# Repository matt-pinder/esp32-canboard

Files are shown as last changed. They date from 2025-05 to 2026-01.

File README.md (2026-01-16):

# ESP32-CANBoard
* ESP32-S3 Dual Core SoC
* MCP2562T CAN Transceiver (up to 1Mbps)
* 10x 5v Tolerant Inputs - Pressure Sensors, NTCs, etc
* 2x 5v Outputs - Fused at 500mA (Thermal Reset)
* USB-C for programming, with JTAG support for debugging
* ESD Protection on both USB and CAN
* JAE Automotive Connector (PCB Socket: MX23A18NF1, Cable Plug: MX23A18SF1)
* Optional pull-up resistors via fused 5v rail for each input (TH 6.3mm)
* Optional 120ohm CAN terminating resistor
* Configuration via web interface over WiFi
* Optional per-channel median filtering to reduce noise
* Small PCB Footprint - 40mm x 60mm

## Device Configuration

On each boot the board enables a WiFi access point and web configuration interface; this will automatically disable after 120 seconds if no client connects. 

| SSID | WPA2 Key | Web UI |
|:---|:---|:---|
| ESP32-CanBoard | canboard123 | http://192.168.4.1 |

The web UI allows you to:

- View and edit per-channel settings (name, sensor type, pull-up, filtering, pressure calibration).
- Configure required CAN parameters - Base ID and bus speed.
- Adjust pullup vref calculation voltage to allow for LDO regulator output/load.
- Backup the entire configuration to a JSON file.
- Restore configuration from a previously exported JSON file.

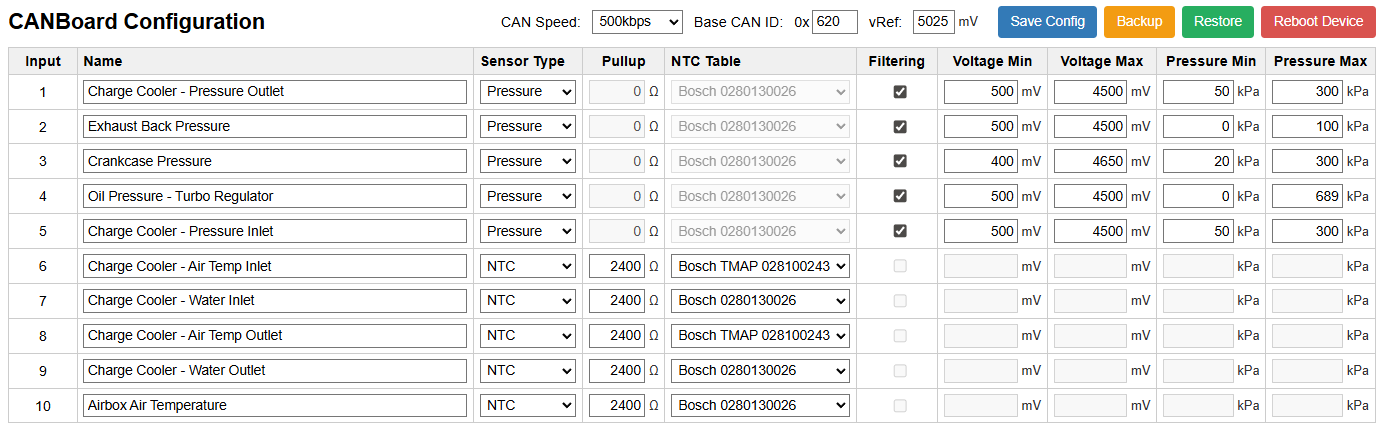
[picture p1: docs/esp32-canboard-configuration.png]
esp32-canboard-configuration


| Function | Description |
|:----|:----|
| Save Config | Save current UI settings to device storage (`/spiffs/config.bin`). Changes are validated and persisted immediately, reboot to apply. |
| Backup | Download a JSON snapshot of the current configuration. The filename is prefixed with `esp32-canboard-config-` and suffixed with the client timestamp in `ddmmyy-hhmmss` format. |
| Restore | Select a previously exported JSON file. The UI will upload the JSON to the device and validate the payload. The existing configuration is backed up on the device before overwrite; if saving the imported file fails, the device will restore the previous configuration. |
| Reboot Device | Reboots the device to apply configuration changes. |

**Notes:**
- Configuration is persisted on SPIFFS at `/spiffs/config.bin` (binary) and the web UI uses JSON export/import for human-readable backups.
- After restoring a new configuration via the web UI you should reboot the device to apply changes.

## CAN Output

The device transmits input data as a set of five CAN frames starting at the configured base ID. All frames use DLC=8 and little-endian byte ordering.

| CAN ID | Name | Payload |
|:---|:---|:---|
| Base ID | analogVoltage_1 | Inputs 0..3 as four uint16 (LSB,MSB) — bytes 0..7 (values in mV) |
| Base ID + 1 | analogVoltage_2 | Inputs 4..7 as four uint16 (LSB,MSB) — bytes 0..7 (values in mV) |
| Base ID + 2 | analogVoltage_3 | Inputs 8..9 as two uint16 (bytes 0..3), dynamic0 (bytes 4..5), dynamic1 (bytes 6..7) |
| Base ID + 3 | dynamicSignals_1 | dynamic2, dynamic3, dynamic4, dynamic5 as four 2-byte values (bytes 0..7) |
| Base ID + 4 | dynamicSignals_2 | dynamic6, dynamic7, dynamic8, dynamic9 as four 2-byte values (bytes 0..7) |

Encoding rules for dynamic values (one per input):
| Channel | Type | Encoding |
|:---|:---|:---|
|analogVoltage|-|unsigned uint16 = voltage * 1000 (resolution 0.001 V)|
|dynamicSignal|Raw|unsigned uint16 = **0** use analogVoltage signal instead|
|dynamicSignal|Pressure|unsigned uint16 = pressure_kPa * 100 (resolution 0.01 kPa)|
|dynamicSignal|NTC|signed int16 = temperature_C * 1 (°C as integer)|

Example DBC for signal names and scaling: [dbc/esp32-canboard.dbc](dbc/esp32-canboard.dbc)

## Schematic
[View PDF](docs/esp32-canboard-schematic.pdf)

## Images
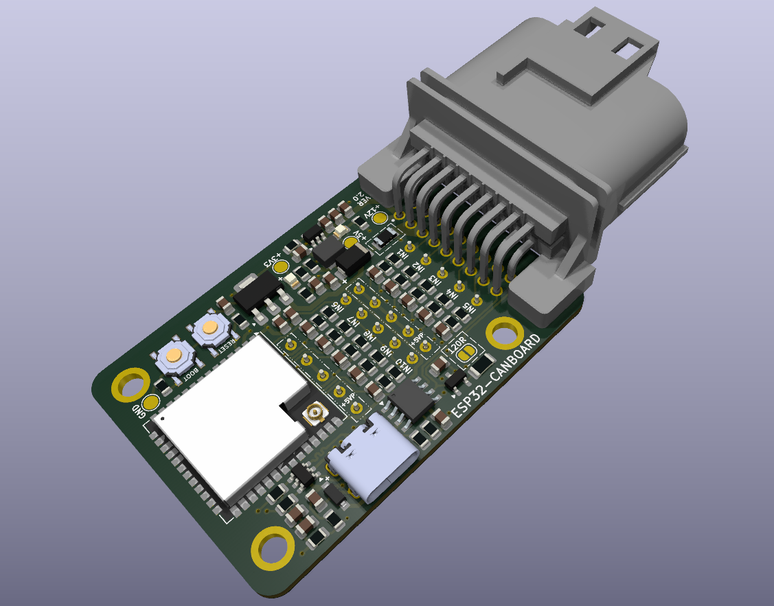
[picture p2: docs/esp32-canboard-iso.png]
esp32-canboard-iso


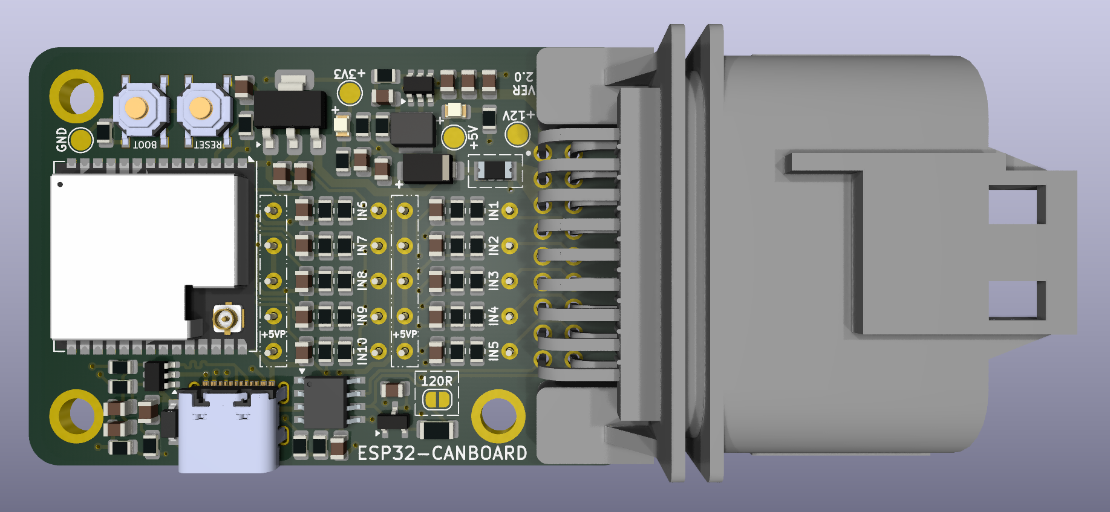
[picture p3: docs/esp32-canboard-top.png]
esp32-canboard-top


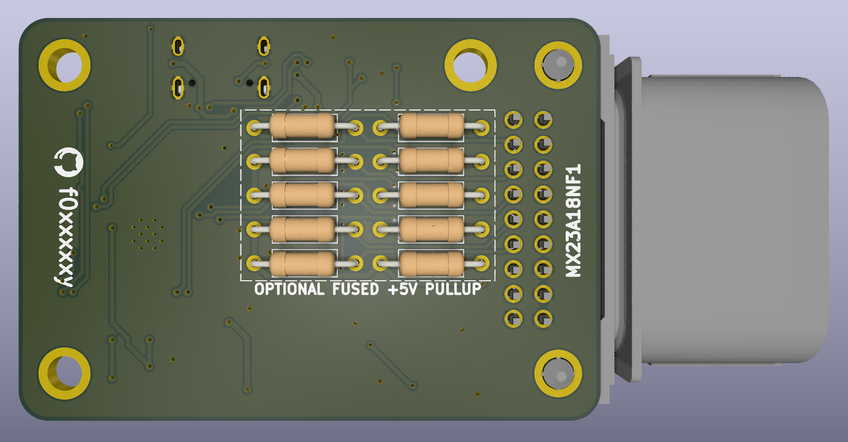
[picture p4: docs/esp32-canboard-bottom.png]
esp32-canboard-bottom


## Connector Pinout
|Pin|Function|Additional Information|
|:---:|:---|:---|
|1|12v Supply||
|2|5v Sensor Supply|500ma Thermal Fuse|
|3|5v Sensor Supply|500ma Thermal Fuse|
|4|Input 6||
|5|Input 7||
|6|Input 8||
|7|Input 9||
|7|Input 10||
|9|CAN High||
|10|Ground||
|11|Ground||
|12|Ground||
|13|Input 1||
|14|Input 2||
|15|Input 3||
|16|Input 4||
|17|Input 5||
|18|CAN Low||

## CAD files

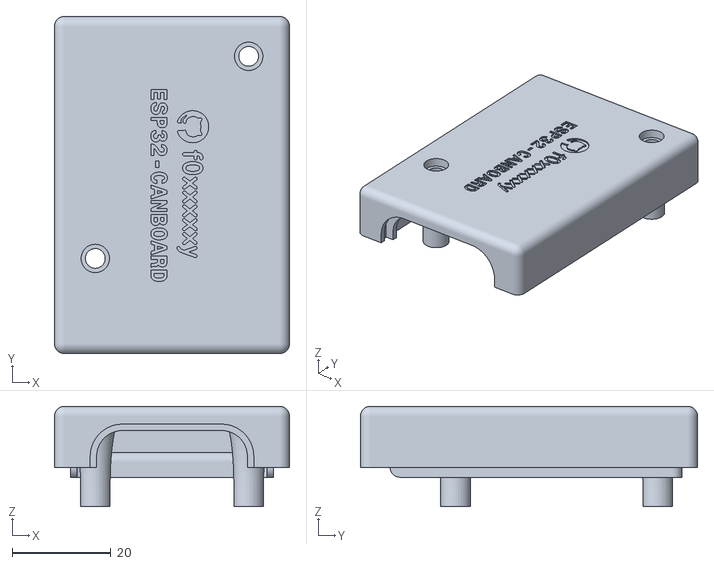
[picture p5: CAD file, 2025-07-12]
hardware/esp32-canboard-case-top.STL
47.5 x 68.2 x 20.3

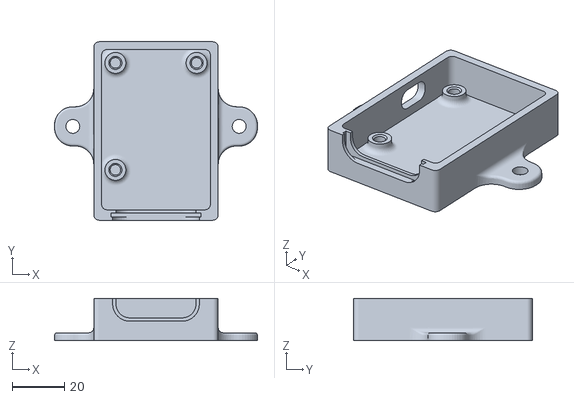
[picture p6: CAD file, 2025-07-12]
hardware/esp32-canboard-case-bottom.STL
77.5 x 68.2 x 16.1

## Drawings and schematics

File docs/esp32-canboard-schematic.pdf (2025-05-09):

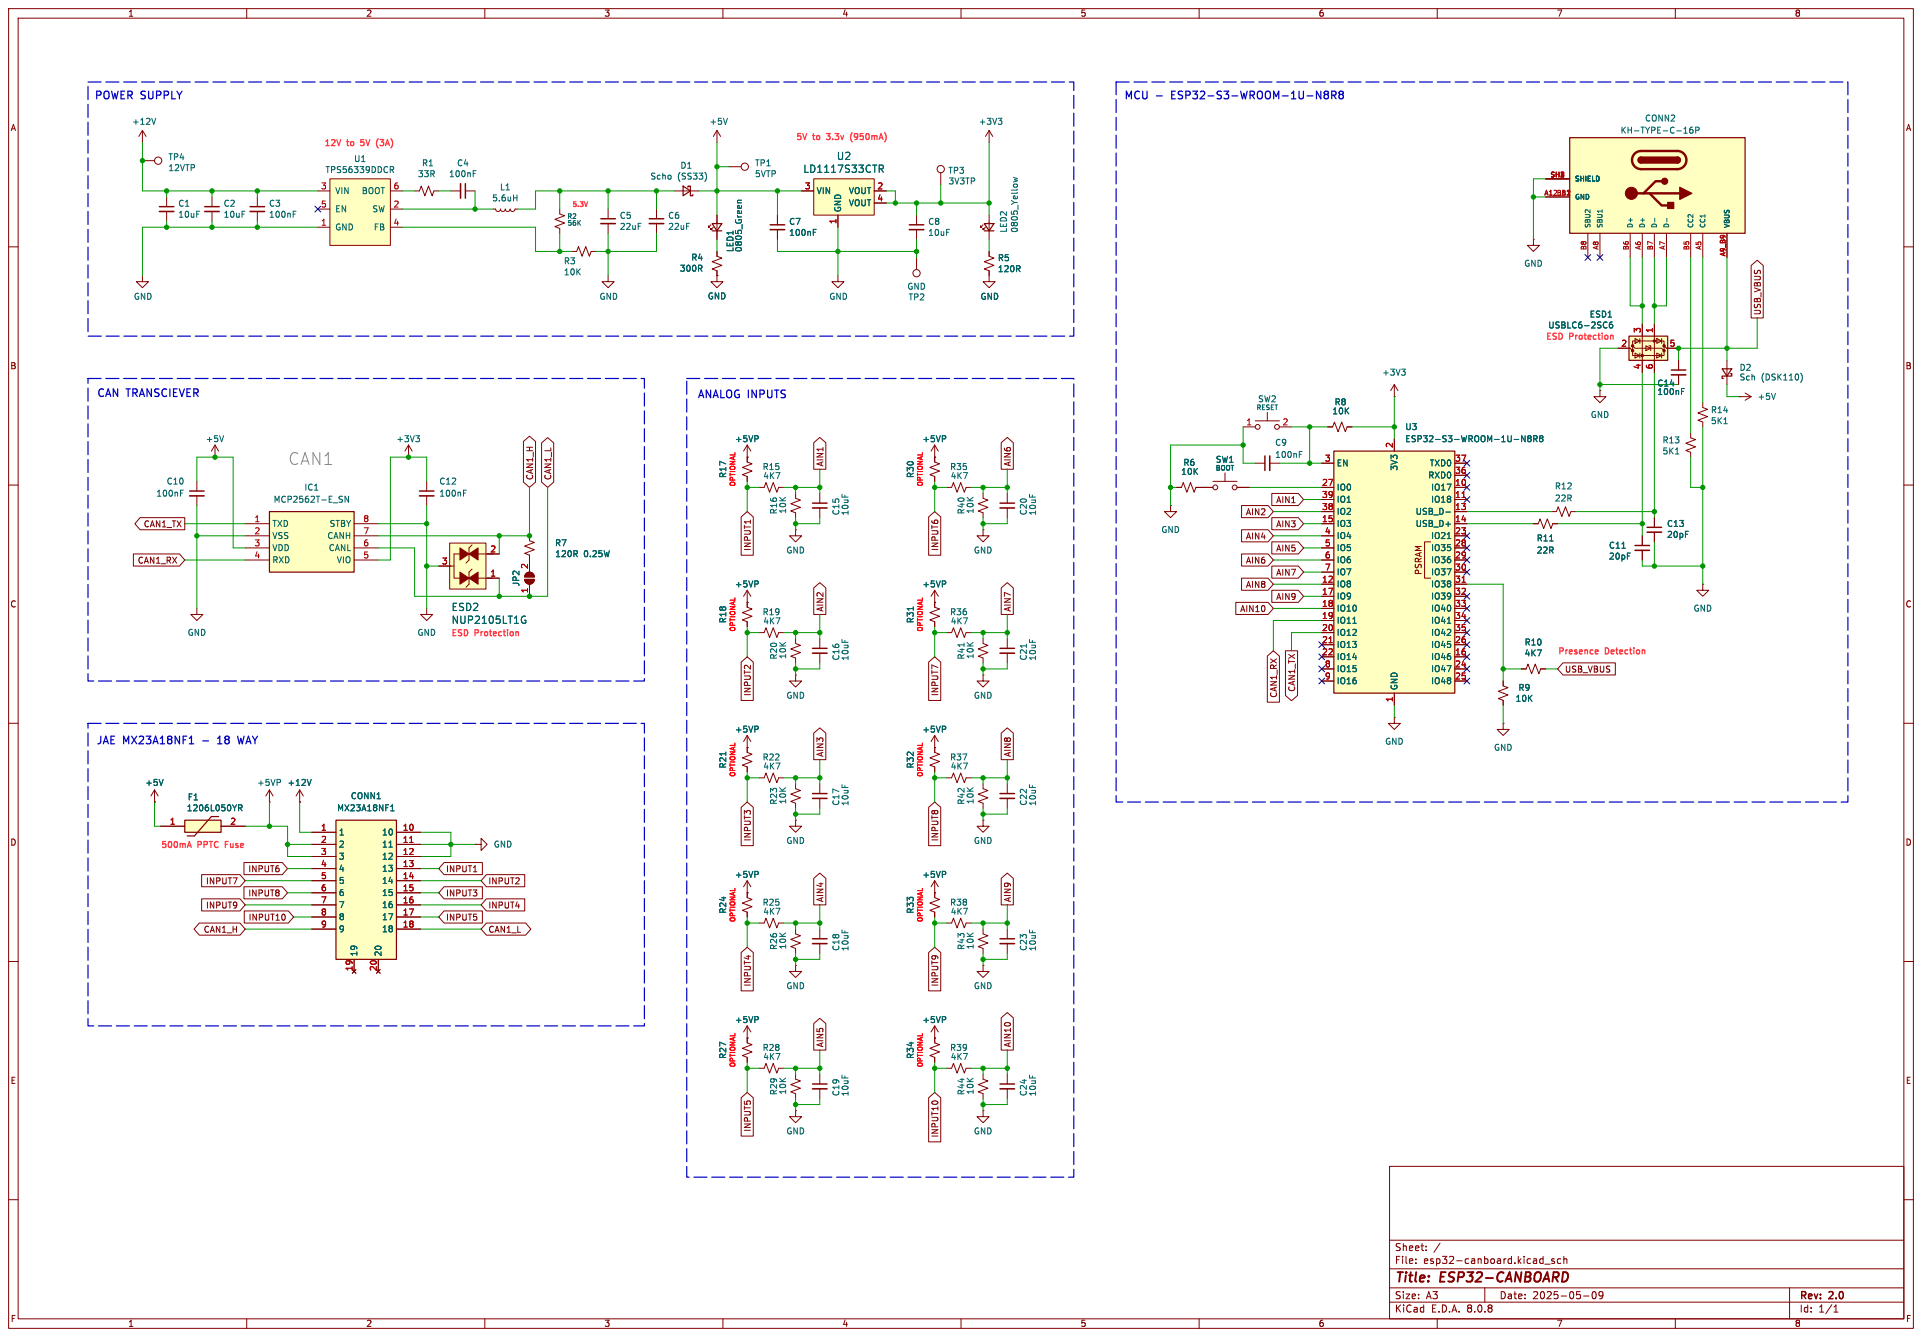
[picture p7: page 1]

6 ESD1 USBLC6-2SC6 R12
Presence Detection ESD Protection

500mA PPTC Fuse JAE MX23A18NF1 - 18 WAY

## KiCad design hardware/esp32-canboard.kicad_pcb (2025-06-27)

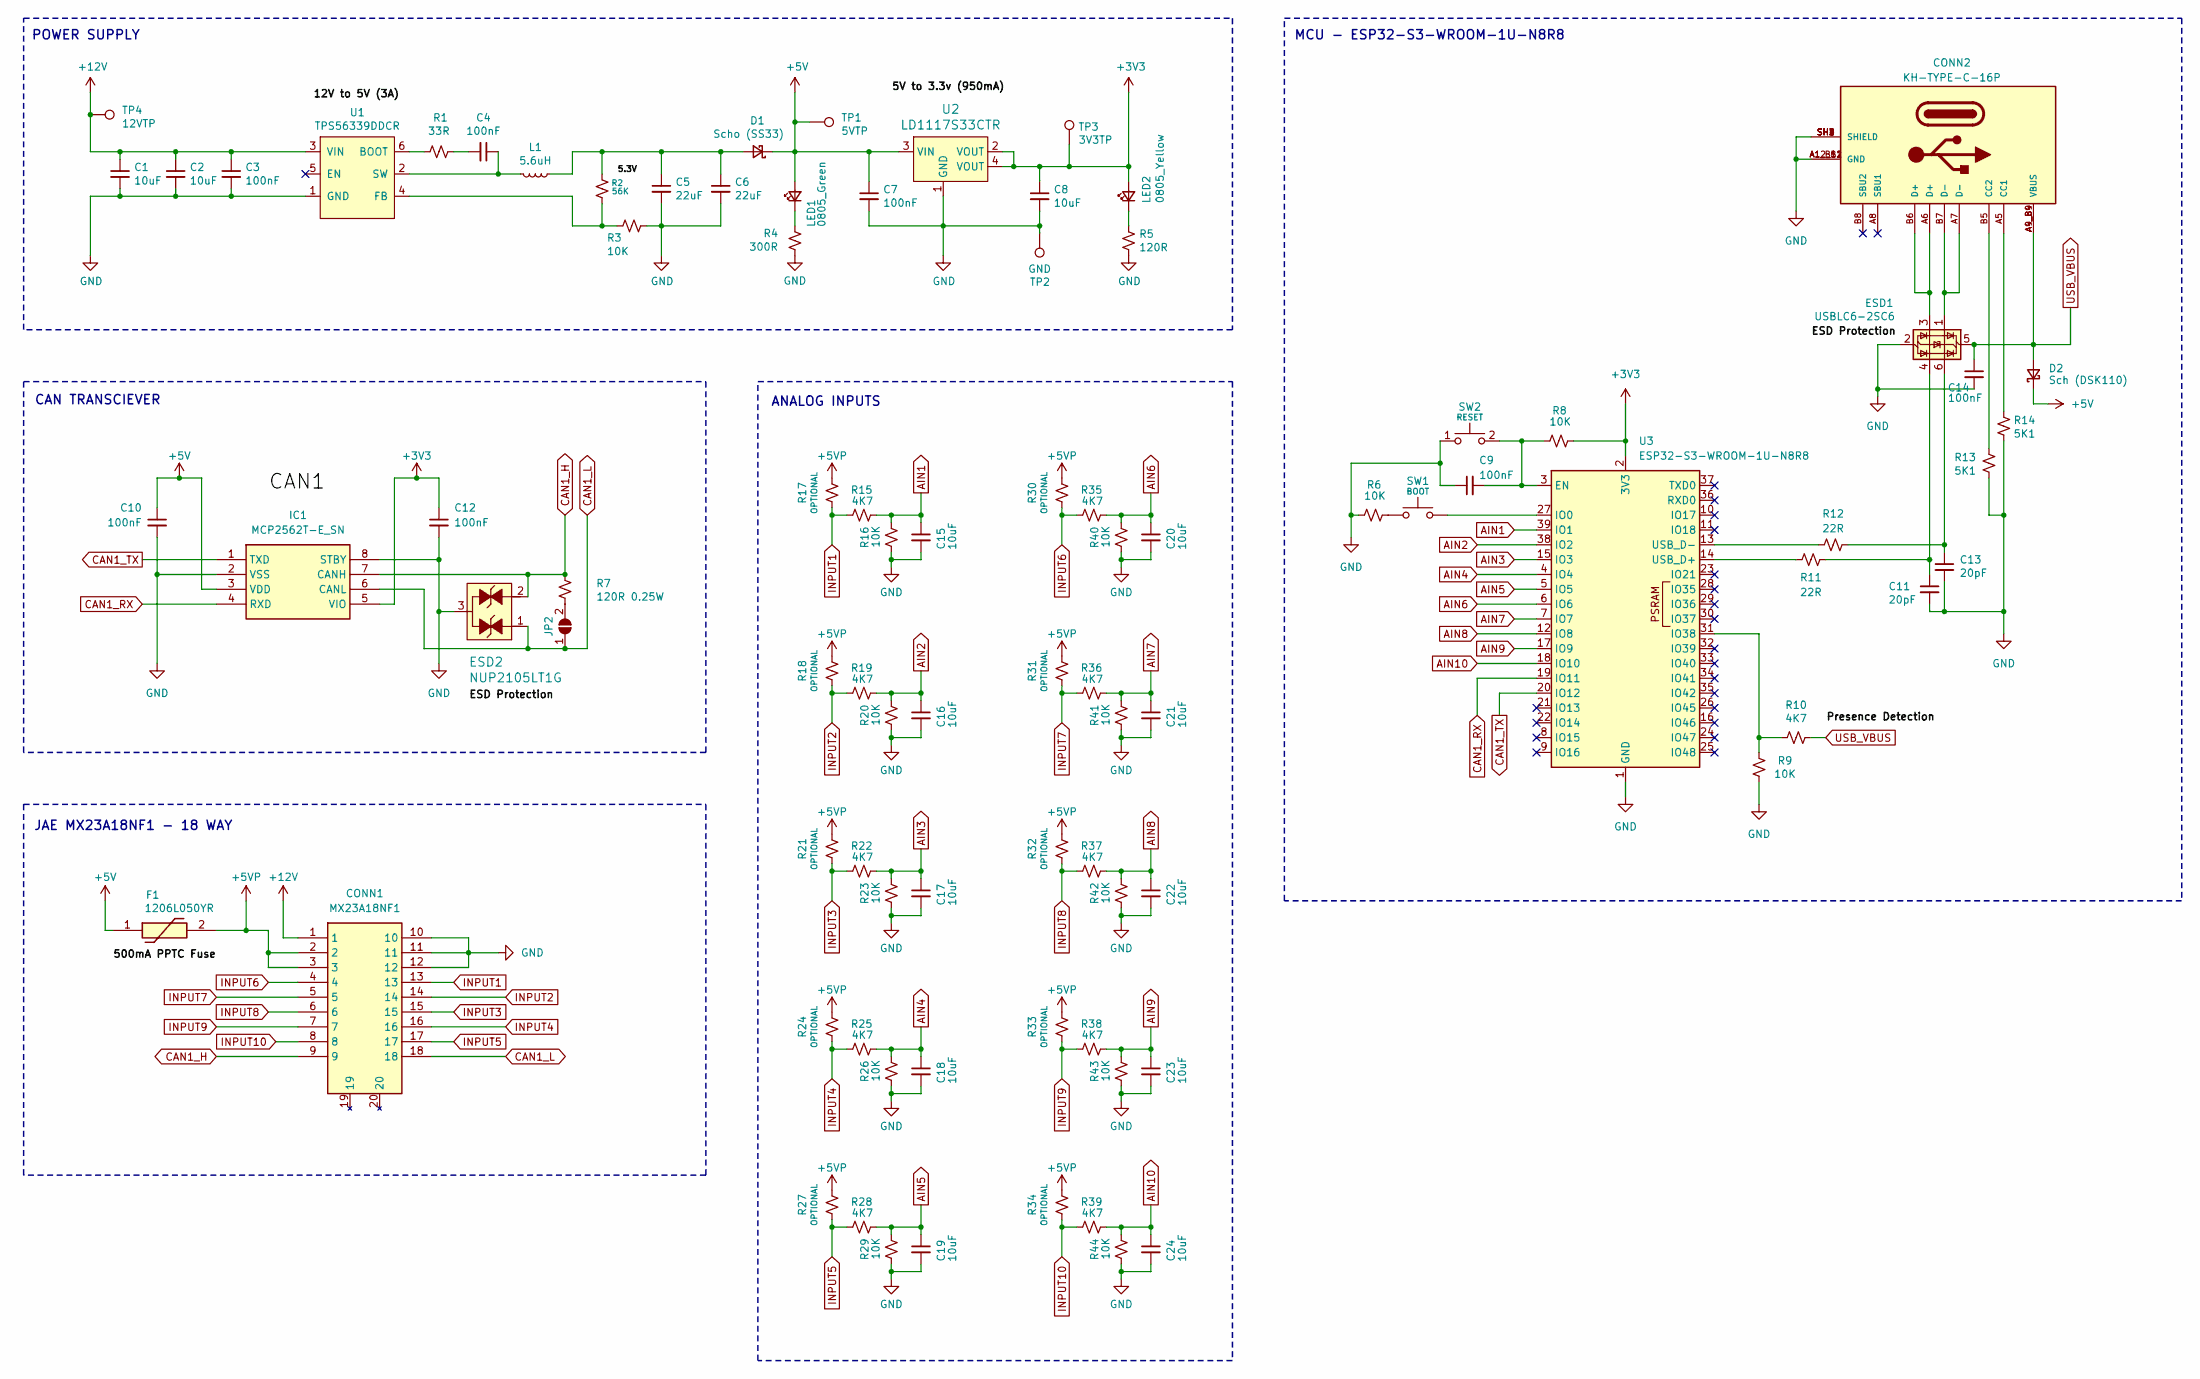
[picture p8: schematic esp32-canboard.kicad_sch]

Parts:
C1, C2, C8, C15, C16, C17, C18, C19, C20, C21, C22, C23, C24: 10uF; C_0805_2012Metric; Digi-Key_PN 490-10748-1-ND
C3, C4, C7, C14: 100nF; C_0805_2012Metric; Digi-Key_PN 399-1169-1-ND
C5, C6: 22uF; C_0805_2012Metric; Digi-Key_PN 445-14560-1-ND
C9, C10, C12: 100nF; C_0805_2012Metric; LCSC C49678
C11, C13: 20pF; C_0805_2012Metric; LCSC C1798
CONN1: MX23A18NF1; Mouser Part Number 656-MX23A18NF1
CONN2: KH-TYPE-C-16P; KINGHELM_KH-TYPE-C-16P; PARTREV A0; LCSC C709357
D1: Scho (SS33); D_SMA; LCSC C28646294
D2: Sch (DSK110); DIODE-SOD-123; LCSC C22466354
ESD1: USBLC6-2SC6; SOT-23-6; Mouser Part Number 511-USBLC6-2SC6
ESD2: NUP2105LT1G; SOT-23-3; MPN NUP2105LT1G; Digi-Key_PN NUP2105LT1GOSCT-ND
F1: 1206L050YR; 1206L05015YR; Mouser Part Number 576-1206L050YR
IC1: MCP2562T-E_SN; SOIC127P600X175-8N; LCSC C191417
JP2: TERM_SB; SolderJumper-2_P1.3mm_Open_RoundedPad1.0x1.5mm
L1: 5.6uH; SMNR4020-5R6MT; Digi-Key_PN 732-3339-1-ND
LED1: 0805_Green; LED_0805_2012Metric; Digi-Key_PN 475-2560-1-ND
LED2: 0805_Yellow; LED_0805_2012Metric; Digi-Key_PN 475-2560-1-ND
R1: 33R; R_0805_2012Metric; Digi-Key_PN RR12Q30DCT-ND
R2: 56K; R_0805_2012Metric; Digi-Key_PN P52.3KCCT-ND
R3: 10K; R_0805_2012Metric; Digi-Key_PN 311-10.0KCRDKR-ND
R4: 300R; R_0805_2012Metric; Digi-Key_PN 311-120CRCT-ND
R5: 120R; R_0805_2012Metric; Digi-Key_PN 311-120CRCT-ND
R6, R8, R9, R16, R20, R23, R26, R29, R40, R41, R42, R43, R44: 10K; R_0805_2012Metric; LCSC C17414
R7: 120R 0.25W; R_1206_3216Metric; Digi-Key_PN A116010CT-ND
R10, R15, R19, R22, R25, R28, R35, R36, R37, R38, R39: 4K7; R_0805_2012Metric; LCSC C17673
R11, R12: 22R; R_0805_2012Metric; LCSC C17561
R13, R14: 5K1; R_0805_2012Metric; Digi-Key_PN 311-5.1KARCT-ND
R17, R18, R21, R24, R27, R30, R31, R32, R33, R34: OPTIONAL; R_Axial_DIN0207_L6.3mm_D2.5mm_P10.16mm_Horizontal
SW1: BOOT; SW_TS-1187A-B-A-B; LCSC C318884
SW2: RESET; SW_TS-1187A-B-A-B; LCSC C318884
TP1: 5VTP; TestPoint_Pad_D2.0mm
TP2: GND; TestPoint_Pad_D2.0mm
TP3: 3V3TP; TestPoint_Pad_D2.0mm
TP4: 12VTP; TestPoint_Pad_D2.0mm
U1: TPS56339DDCR; SOT-23-6; Digi-Key_PN 296-53568-1-ND
U2: LD1117S33CTR; SOT-223; MPN LD1117S33CTR; Digi-Key_PN 497-1241-1-ND
U3: ESP32-S3-WROOM-1U-N8R8; ESP32-S3-WROOM-1U; LCSC C2980300

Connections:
+3V3: C8.1, C12.1, IC1.5 (VIO), LED2.2 (A), R8.1, TP3.1, U2.2 (VOUT), U2.4 (VOUT), U3.2 (3V3)
+5V: C7.1, C10.1, D1.1 (K), D2.1 (K), F1.1, IC1.3 (VDD), LED1.2 (A), TP1.1, U2.3 (VIN)
+5VP: CONN1.2, CONN1.3, F1.2, R17.1, R18.1, R21.1, R24.1, R27.1, R30.1, R31.1, R32.1, R33.1, R34.1
+12V: C1.1, C2.1, C3.1, CONN1.1, TP4.1, U1.3 (VIN)
AIN1: C15.1, R15.1, R16.1, U3.39 (IO1)
AIN2: C16.1, R19.1, R20.1, U3.38 (IO2)
AIN3: C17.1, R22.1, R23.1, U3.15 (IO3)
AIN4: C18.1, R25.1, R26.1, U3.4 (IO4)
AIN5: C19.1, R28.1, R29.1, U3.5 (IO5)
AIN6: C20.1, R35.1, R40.1, U3.6 (IO6)
AIN7: C21.1, R36.1, R41.1, U3.7 (IO7)
AIN8: C22.1, R37.1, R42.1, U3.12 (IO8)
AIN9: C23.1, R38.1, R43.1, U3.17 (IO9)
AIN10: C24.1, R39.1, R44.1, U3.18 (IO10)
CAN1_H: CONN1.9, ESD2.2, IC1.7 (CANH), R7.2
CAN1_L: CONN1.18, ESD2.1, IC1.6 (CANL), JP2.1 (A)
CAN1_RX: IC1.4 (RXD), U3.19 (IO11)
CAN1_TX: IC1.1 (TXD), U3.20 (IO12)
GND: C1.2, C2.2, C3.2, C5.2, C6.2, C7.2, C8.2, C9.1, C10.2, C11.2, C12.2, C13.2, C14.2, C15.2, C16.2, C17.2, C18.2, C19.2, C20.2, C21.2, C22.2, C23.2, C24.2, CONN1.10, CONN1.11, CONN1.12, CONN2.A1_B12 (GND), CONN2.A12_B1 (GND), CONN2.SH1 (SHIELD), CONN2.SH2 (SHIELD), CONN2.SH3 (SHIELD), CONN2.SH4 (SHIELD), ESD1.2 (GND), ESD2.3, IC1.2 (VSS), IC1.8 (STBY), R3.2, R4.1, R5.1, R6.2, R9.2, R13.2, R14.2, R16.2, R20.2, R23.2, R26.2, R29.2, R40.2, R41.2, R42.2, R43.2, R44.2, SW2.1, TP2.1, U1.1 (GND), U2.1 (GND), U3.1 (GND), U3.40 (GND), U3.41 (GND)
INPUT1: CONN1.13, R15.2, R17.2
INPUT2: CONN1.14, R18.2, R19.2
INPUT3: CONN1.15, R21.2, R22.2
INPUT4: CONN1.16, R24.2, R25.2
INPUT5: CONN1.17, R27.2, R28.2
INPUT6: CONN1.4, R30.2, R35.2
INPUT7: CONN1.5, R31.2, R36.2
INPUT8: CONN1.6, R32.2, R37.2
INPUT9: CONN1.7, R33.2, R38.2
INPUT10: CONN1.8, R34.2, R39.2
unnamed: C4.2, R1.1
unnamed: C11.1, ESD1.4 (I/O2), R11.2
unnamed: C13.1, ESD1.6 (I/O1), R12.2
unnamed: CONN2.A5 (CC1), R14.1
unnamed: CONN2.B5 (CC2), R13.1
unnamed: CONN2.A6 (D+), CONN2.B6 (D+), ESD1.3 (I/O2)
unnamed: CONN2.A7 (D-), CONN2.B7 (D-), ESD1.1 (I/O1)
unnamed: C5.1, C6.1, D1.2 (A), L1.1, R2.2
unnamed: JP2.2 (B), R7.1
unnamed: LED1.1 (K), R4.2
unnamed: LED2.1 (K), R5.2
unnamed: R6.1, SW1.1
unnamed: R1.2, U1.6 (BOOT)
unnamed: R2.1, R3.1, U1.4 (FB)
unnamed: C4.1, L1.2, U1.2 (SW)
unnamed: C9.2, R8.2, SW2.2, U3.3 (EN)
unnamed: SW1.2, U3.27 (IO0)
unnamed: R9.1, R10.1, U3.31 (IO38)
unnamed: R11.1, U3.14 (USB_D+)
unnamed: R12.1, U3.13 (USB_D-)
USB_VBUS: C14.1, CONN2.A4_B9 (VBUS), CONN2.A9_B4 (VBUS), D2.2 (A), ESD1.5 (VBUS), R10.2

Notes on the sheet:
JAE MX23A18NF1 - 18 WAY
MCU - ESP32-S3-WROOM-1U-N8R8
ANALOG INPUTS
POWER SUPPLY
CAN TRANSCIEVER

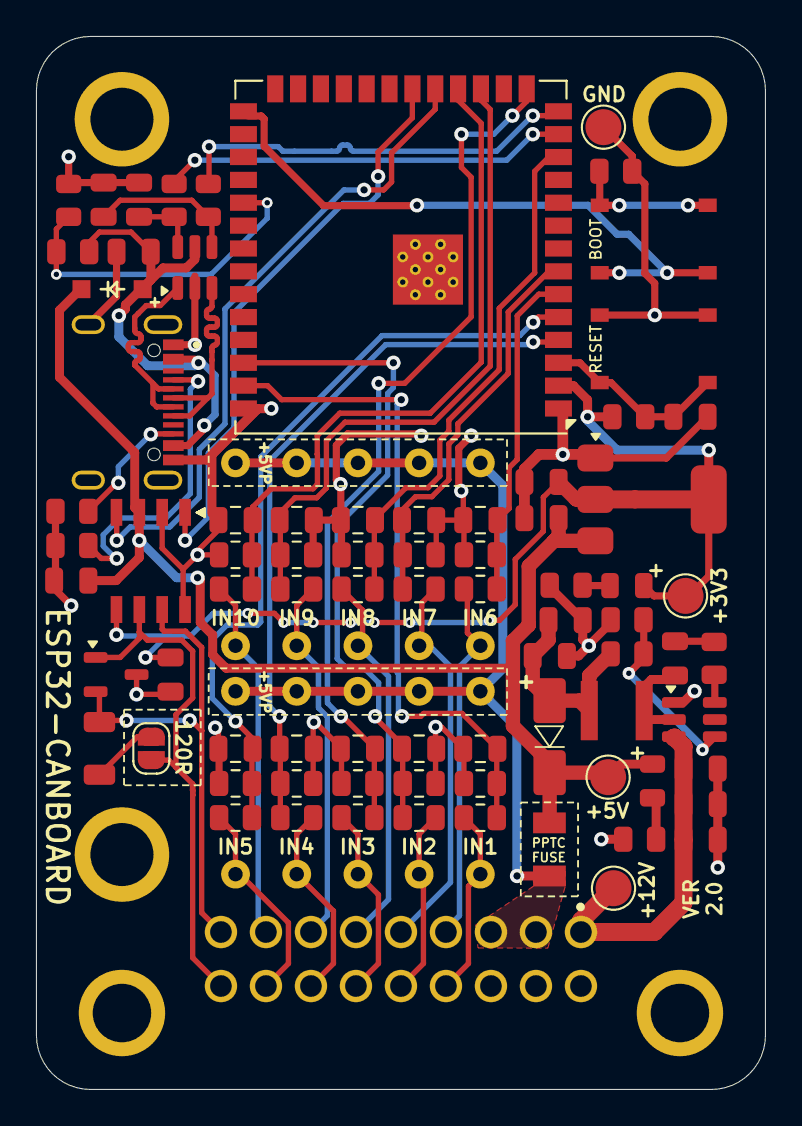
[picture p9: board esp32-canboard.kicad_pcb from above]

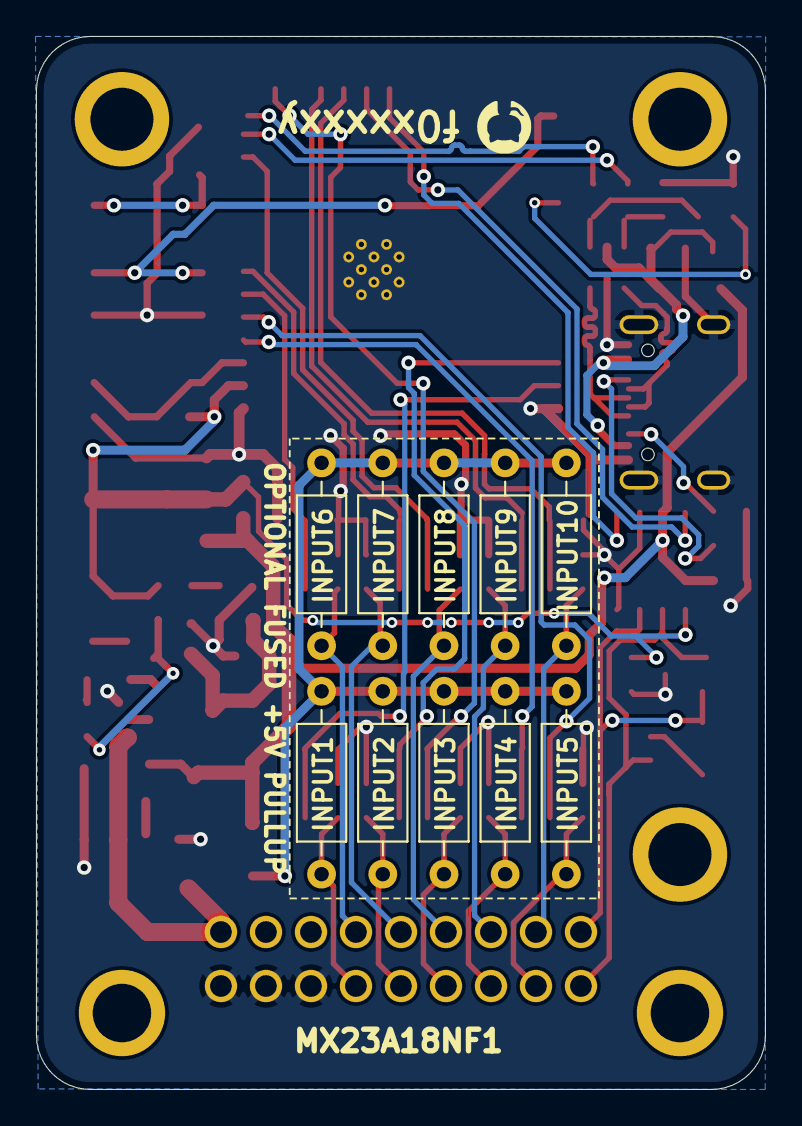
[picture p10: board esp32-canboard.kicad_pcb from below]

Board: 2 copper layers, 40.5 x 58.5 mm, 92 parts (10 on the bottom side), 50 nets.

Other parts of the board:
MH1: MH1
MH2: MH2
MH3: MH3

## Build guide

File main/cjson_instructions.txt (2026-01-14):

# cJSON for ESP-IDF
# Add this to your CMakeLists.txt or component.mk as needed
# https://github.com/DaveGamble/cJSON

set(CJSON_DIR ${CMAKE_CURRENT_SOURCE_DIR}/../components/cJSON)
set(CJSON_SOURCES ${CJSON_DIR}/cJSON.c)

add_library(cjson STATIC ${CJSON_SOURCES})
target_include_directories(cjson PUBLIC ${CJSON_DIR})

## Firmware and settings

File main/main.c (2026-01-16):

#include <stdio.h>
#include <stdlib.h>
#include <stdbool.h>
#include <stddef.h>
#include <string.h>
#include <time.h>
#include <sys/time.h>

#include "freertos/FreeRTOS.h"
#include "freertos/task.h"
#include "freertos/semphr.h"

#include "esp_err.h"
#include "esp_log.h"
#include "esp_system.h"
#include "driver/gpio.h"
#include "driver/twai.h"

#define USB_PRESENCE_DETECT GPIO_NUM_38

#include "inc/inputs.h"
#include "inc/can.h"

#include "inc/wifi_config.h"
#include "inc/config.h"
#include "esp_spiffs.h"

// Global board configuration (shared with other modules)
board_config_t board_cfg;

void app_main(void)
{
    static const char *log_tag = "APP";
    
    // Load board config from SPIFFS (with CRC check)
    // Ensure SPIFFS is mounted so config_load/config_save can access files
    esp_err_t spiffs_ret = esp_vfs_spiffs_register(&(esp_vfs_spiffs_conf_t){
        .base_path = "/spiffs",
        .partition_label = NULL,
        .max_files = 5,
        .format_if_mount_failed = true
    });
    if (spiffs_ret == ESP_ERR_INVALID_STATE) {
        ESP_LOGI(log_tag, "SPIFFS already mounted");
    } else if (spiffs_ret != ESP_OK) {
        ESP_LOGW(log_tag, "Failed to mount SPIFFS: %s", esp_err_to_name(spiffs_ret));
    } else {
        ESP_LOGI(log_tag, "SPIFFS mounted for config access");
    }
    if (!config_load(&board_cfg)) {
        ESP_LOGW(log_tag, "Config CRC invalid or not found, using defaults");
        config_set_defaults(&board_cfg);
        if (!config_save(&board_cfg)) {
            ESP_LOGE(log_tag, "Failed to save default config!");
        }
    } else {
        ESP_LOGI(log_tag, "Config loaded and CRC valid");
    }

    // Start WiFi config mode (AP + HTTP server with timeout)
    wifi_config_mode_start();
    
    // Initialize CPU temperature sensor
    esp_err_t err = initCpuTempSensor();
    if (err != ESP_OK) {
        ESP_LOGW(log_tag, "Failed to initialize CPU temp sensor: %s", esp_err_to_name(err));
    } else {
        int8_t cpu_temp = getCpuTemperature();
        ESP_LOGI(log_tag, "Current CPU Temperature: %d°C", cpu_temp);
    }

    // Initialize ADC channels
    initAdcChannels();

    // Initialize TWAI/CAN driver with dynamic speed from config
    if (can_init() != ESP_OK) {
        ESP_LOGE(log_tag, "Failed to initialize CAN driver!");
        abort();
    }

    // Create mutex for protecting filtered voltage array
    filtered_voltages_mutex = xSemaphoreCreateMutex();
    if (filtered_voltages_mutex == NULL) {
        ESP_LOGE(log_tag, "Failed to create voltage mutex! Aborting...");
        abort();
    }

    // Process ADCs on Core 1
    BaseType_t task_result = xTaskCreatePinnedToCore(
        adcProcess, "adcProcess", 8192, NULL, 5, NULL, 1);
    if (task_result != pdPASS) {
        ESP_LOGE(log_tag, "Failed to create ADC processing task!");
        abort();
    }

    // Transmit CAN on Core 0
    task_result = xTaskCreatePinnedToCore(
        canTransmit, "canTransmit", 8192, NULL, 10, NULL, 0);
    if (task_result != pdPASS) {
        ESP_LOGE(log_tag, "Failed to create CAN transmit task!");
        abort();
    }
    
    ESP_LOGI(log_tag, "System initialization complete");
}

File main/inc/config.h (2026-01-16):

#ifndef CONFIG_H
#define CONFIG_H

#include <stdint.h>
#include <stdbool.h>

#define CONFIG_CHANNELS 10       ///< Number of ADC input channels
#define CONFIG_NAME_LEN 32      ///< Maximum characters for channel name
#define CONFIG_VERSION 2        ///< Configuration structure version number

/// Sensor measurement types for ADC channels
typedef enum {
    SENSOR_RAW = 0,
    SENSOR_NTC = 1,
    SENSOR_PRESSURE = 2
} sensor_type_t;

/// Per-channel configuration structure
typedef struct {
    char name[CONFIG_NAME_LEN]; ///< ASCII name/description of the channel
    uint32_t pullup_ohms;       ///< Optional pullup resistor value in ohms (0 if not present)
    sensor_type_t type;         ///< Sensor type (RAW, NTC, PRESSURE)
    uint8_t filtering;          ///< Enable median filtering (1=enabled, 0=raw ADC)
    union {
        struct { ///< NTC thermistor configuration
            uint8_t table_id;   ///< Reference table index for NTC lookup
        } ntc;
        struct { ///< Pressure sensor configuration
            uint16_t min_mv;    ///< Minimum voltage in millivolts
            uint16_t max_mv;    ///< Maximum voltage in millivolts
            float min_kpa;      ///< Minimum pressure in kilopascals
            float max_kpa;      ///< Maximum pressure in kilopascals
        } pressure;
        struct { ///< Raw voltage measurement (no conversion)
        } raw;
    } params;
} channel_config_t;

/// Main board configuration structure persisted to SPIFFS
typedef struct {
    uint32_t version;                      ///< Config version for migration/compatibility
    uint32_t can_start_id;                 ///< CAN message ID base (incremented for each message)
    uint32_t can_speed_kbps;               ///< CAN bus speed (125, 250, 500, or 1000 kbps)
    uint16_t pullup_vref_mv;               ///< Pull-up reference voltage in millivolts (e.g. 5025)
    channel_config_t channels[CONFIG_CHANNELS]; ///< Per-channel configuration array
    uint32_t crc32;                        ///< CRC32 checksum of all fields above for integrity verification
} board_config_t;

/// @brief Persist board configuration to SPIFFS with CRC32 verification
/// @param cfg Pointer to configuration structure to save
/// @return true if save successful, false on SPIFFS error
bool config_save(const board_config_t *cfg);

/// @brief Load and validate board configuration from SPIFFS
/// @param cfg Pointer to configuration structure to populate
/// @return true if load successful and CRC valid, false on SPIFFS error or corruption
bool config_load(board_config_t *cfg);

/// @brief Initialize configuration structure with factory defaults
/// @param cfg Pointer to configuration structure to initialize
void config_set_defaults(board_config_t *cfg);

#endif // CONFIG_H

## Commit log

2025-06-25 Remove legacy ADC reference
2025-06-27 Sensor calibrations
2025-06-27 Output Pressures
2025-06-27 Corrected pullup rear silkscreen numbering
    [BOM-esp32-canboard-jlcpcb.csv, Body1.SLDPRT, Body2.SLDPRT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]
2025-06-27 Clamp maximum temperature
2025-07-03 Calibrations and CAN Outputs
2025-07-06 Return pressure 0 if voltage 0
2025-07-06 Change turbo pressure to bar
2025-07-09 Added optional ADC filtering
2025-07-12 Case STLs
    [esp32-canboard-case-bottom.STL, esp32-canboard-case-top.STL]
2025-07-13 Charge Cooler Quadratic Equation
2025-07-14 Switch Turbo Oil Pressure Sensor
2025-07-15 Scaled Pressure Changes
2025-07-18 TMAP and CC Pressure Changes
2026-01-14 Initial release
    [partitions.csv]
2026-01-16 Added NTC sensor
